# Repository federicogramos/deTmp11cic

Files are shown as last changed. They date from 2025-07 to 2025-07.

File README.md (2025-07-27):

# About
Dispositivo de control periódico.
- Firmware
- Pcb diseño altium de varias placas que componen distintas partes.
- Fuente de alimentacion switching step down diseñada aparte en otro proyecto aun no incluido.

# ./sw
Contiene el firmware para ser utilizado en el hw aqui especificado.

# Schematics
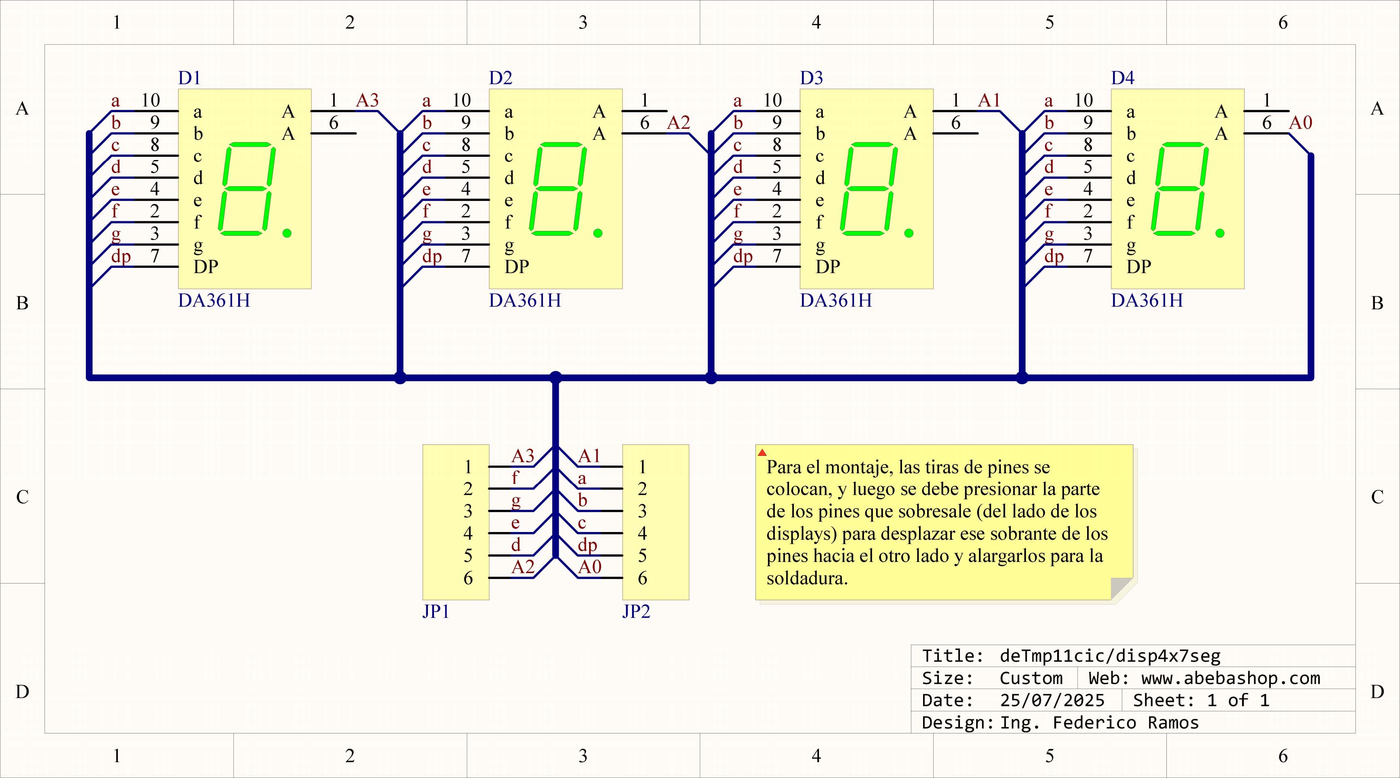
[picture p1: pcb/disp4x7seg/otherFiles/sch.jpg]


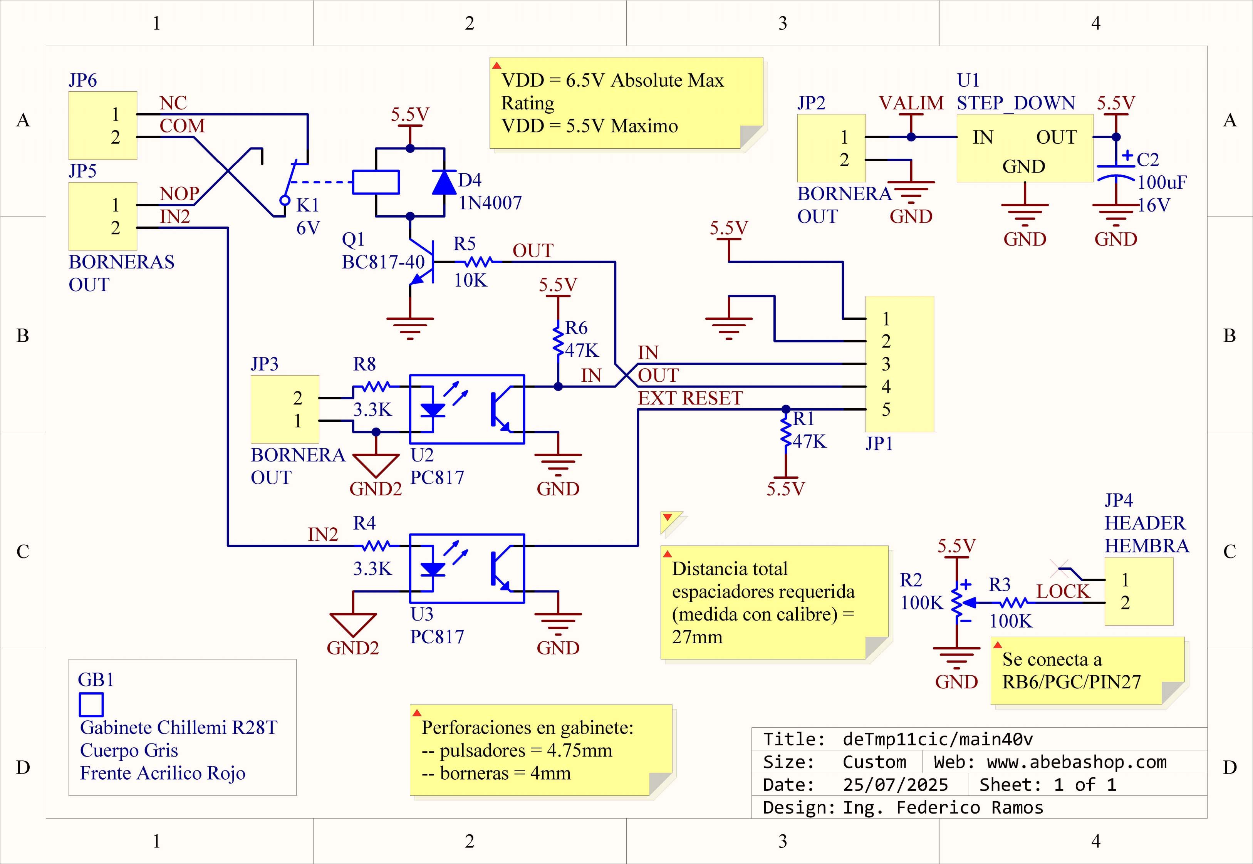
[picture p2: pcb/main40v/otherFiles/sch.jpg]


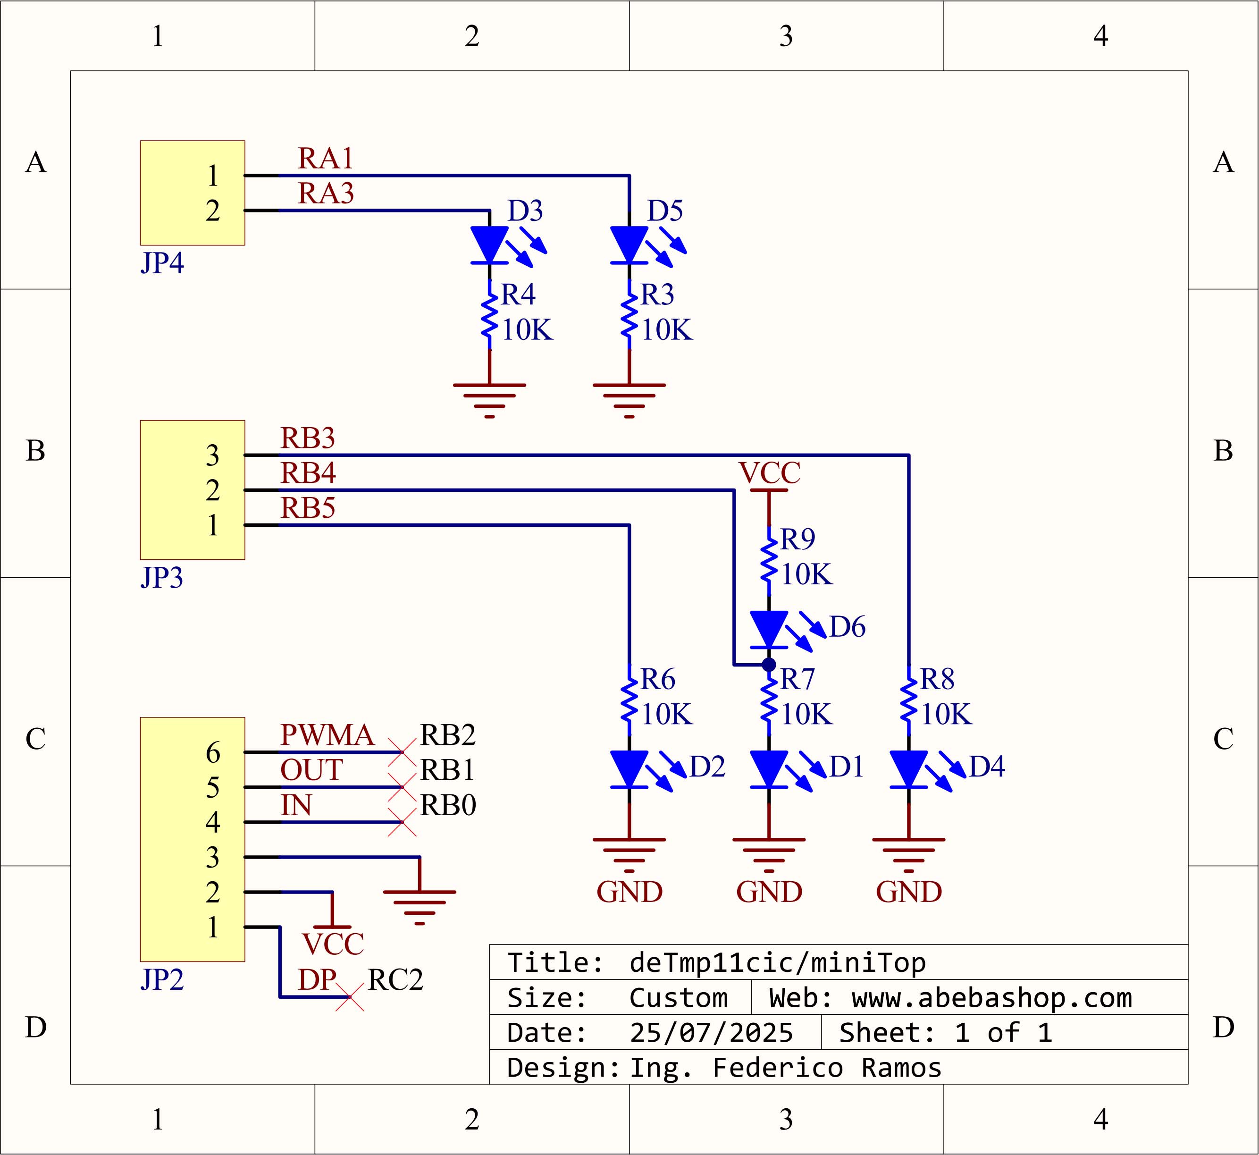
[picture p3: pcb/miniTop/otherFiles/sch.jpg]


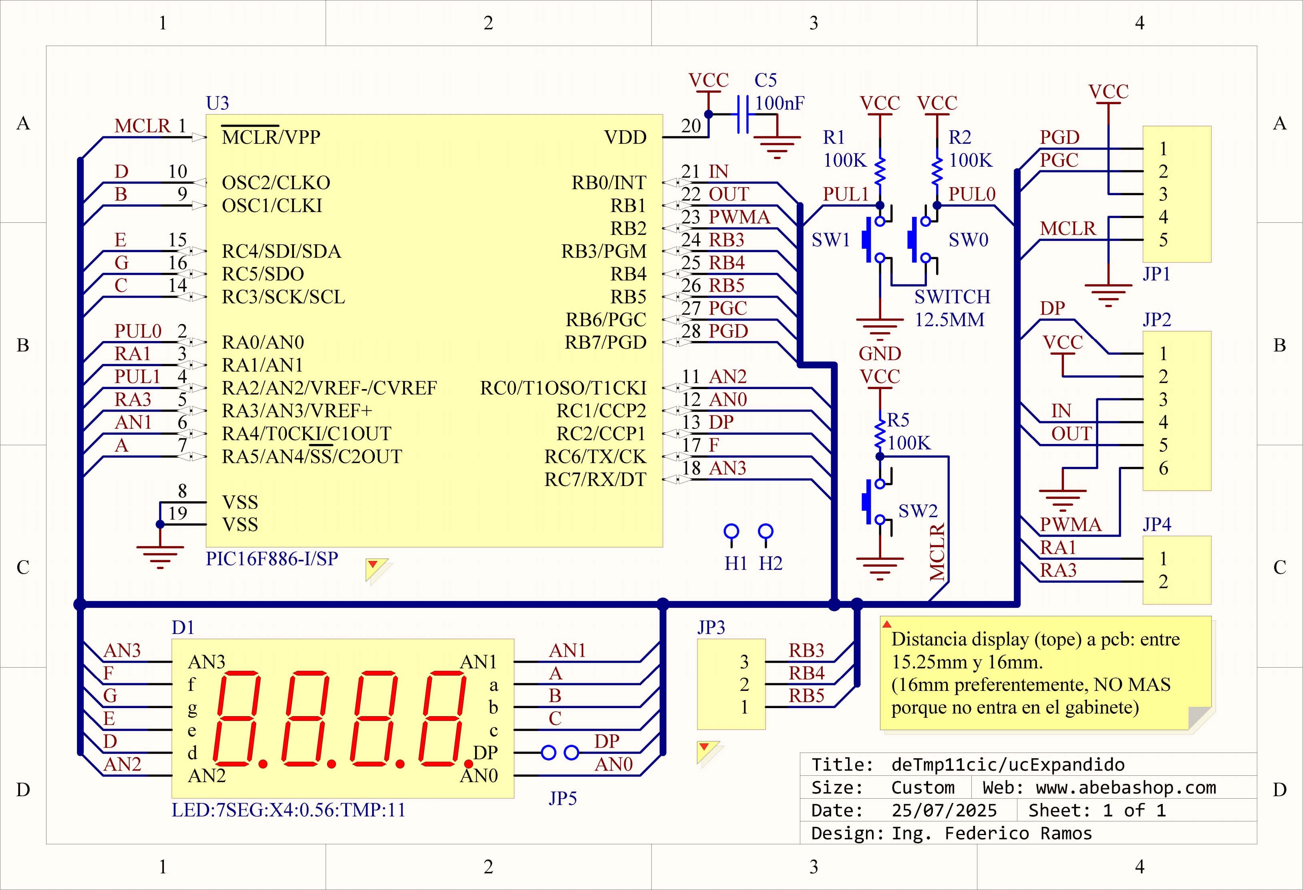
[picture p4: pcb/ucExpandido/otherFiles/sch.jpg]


# PCBs

### ucExpandido

Bottom overlay
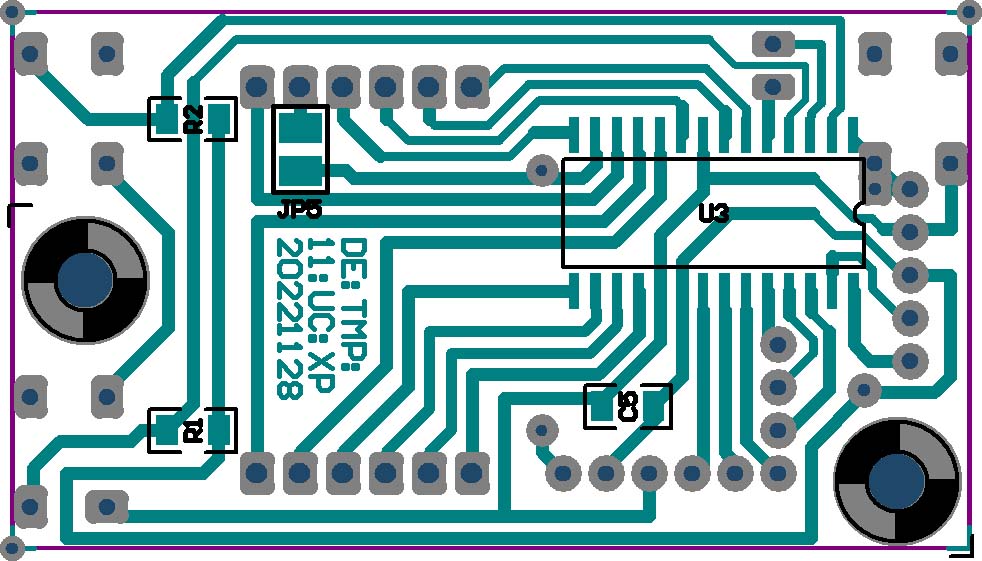
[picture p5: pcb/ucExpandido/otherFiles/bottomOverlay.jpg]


Top overlay
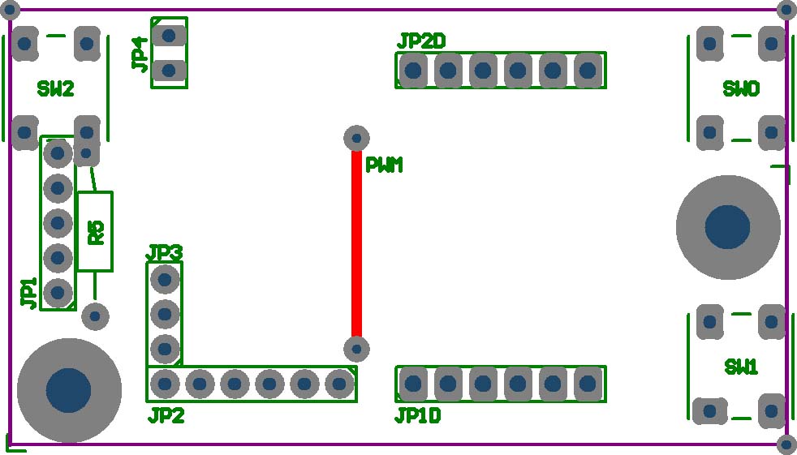
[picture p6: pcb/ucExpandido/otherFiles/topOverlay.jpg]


# Renderización cad
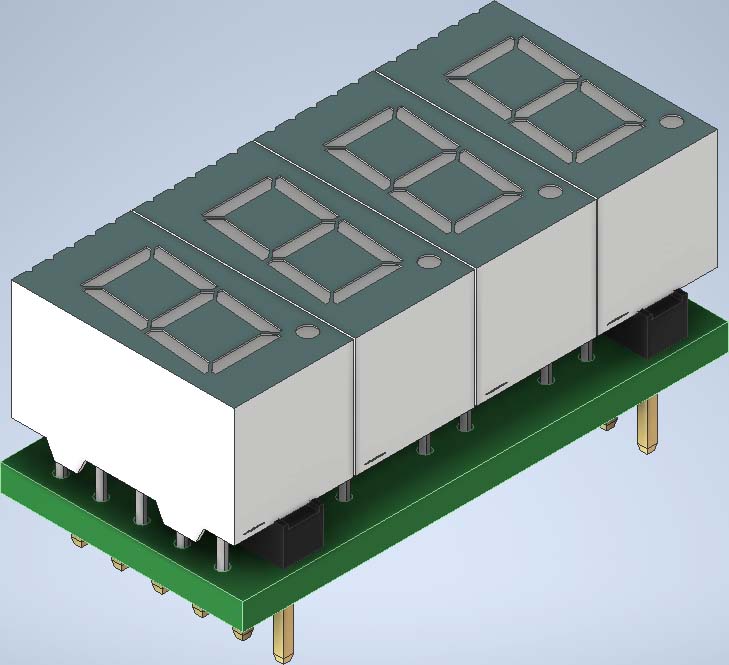
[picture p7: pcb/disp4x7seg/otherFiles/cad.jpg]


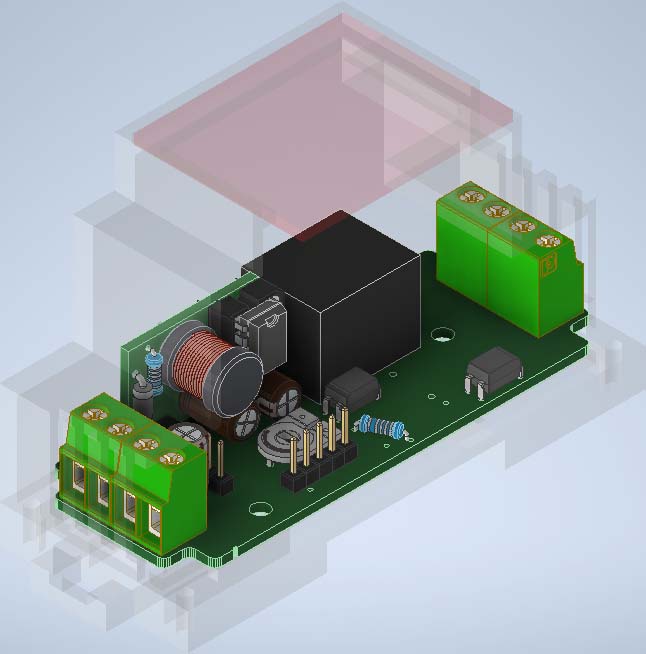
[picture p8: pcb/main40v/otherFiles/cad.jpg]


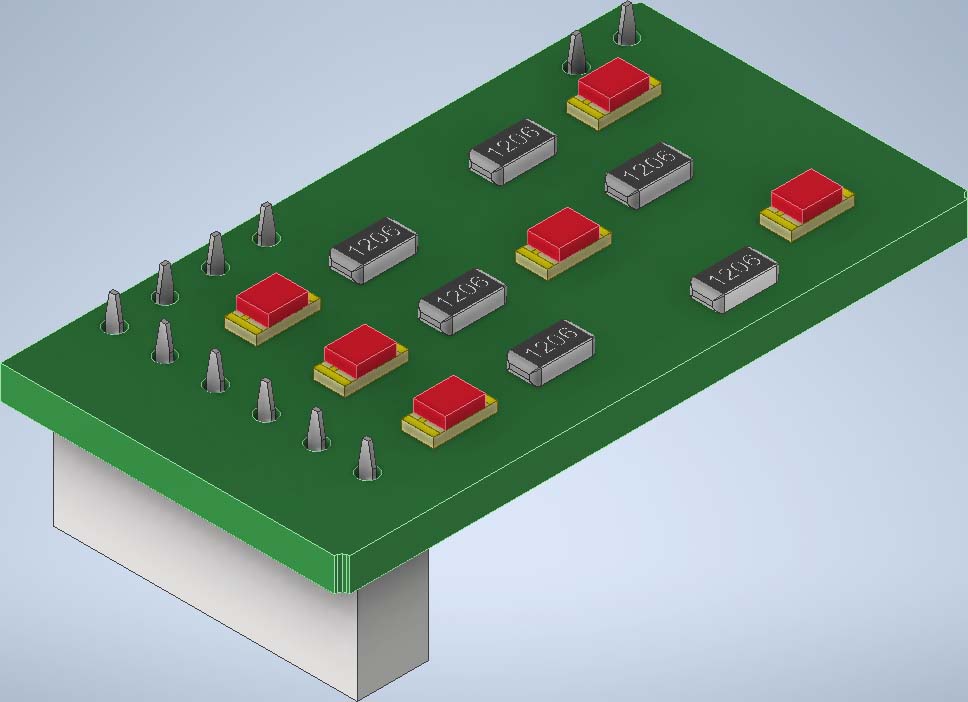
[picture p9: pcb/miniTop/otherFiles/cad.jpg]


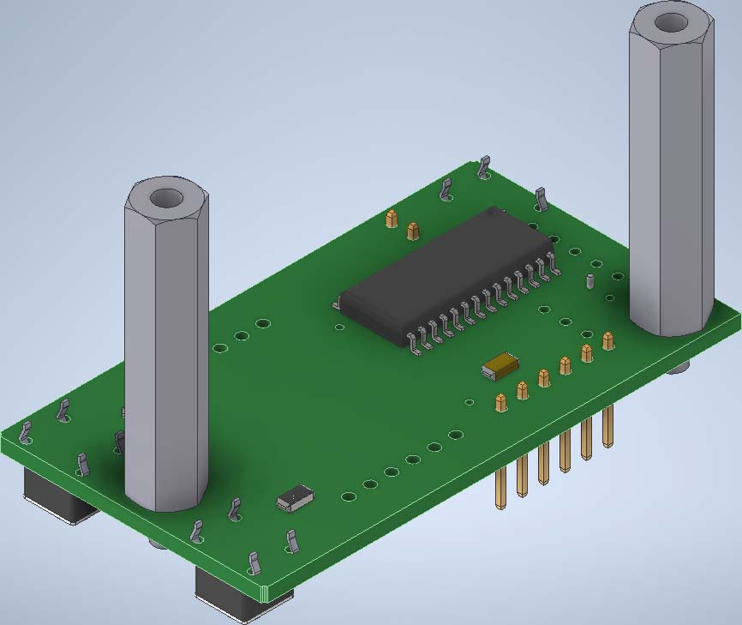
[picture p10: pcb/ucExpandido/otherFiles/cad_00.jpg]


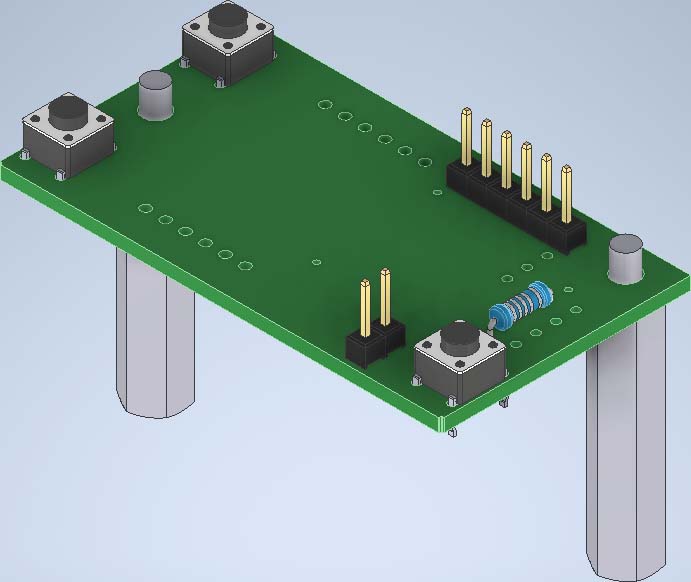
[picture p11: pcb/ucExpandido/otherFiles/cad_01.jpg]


# Modulos ensamblados

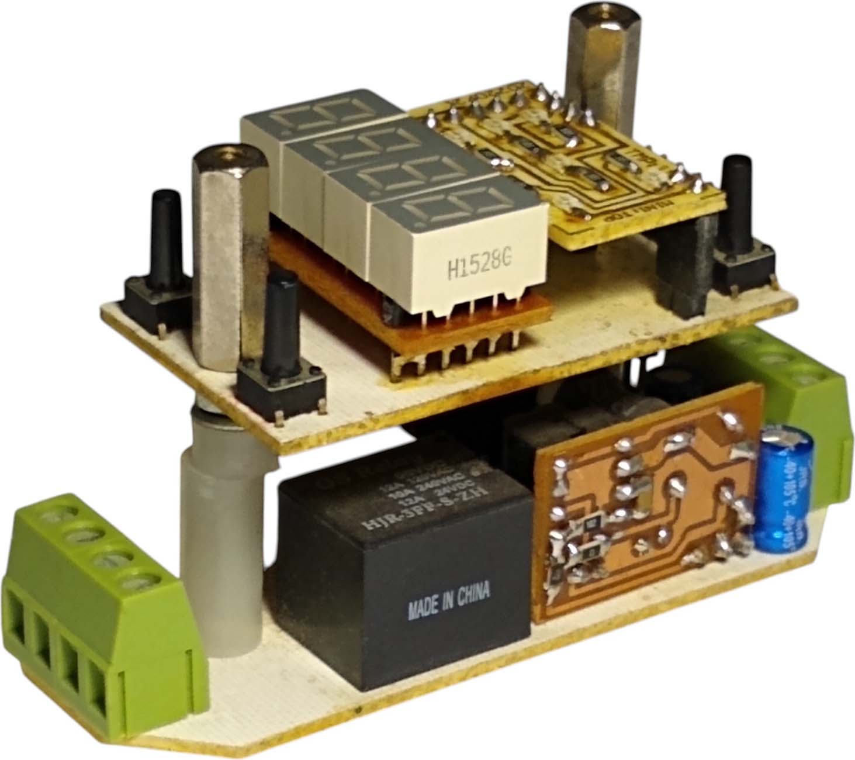
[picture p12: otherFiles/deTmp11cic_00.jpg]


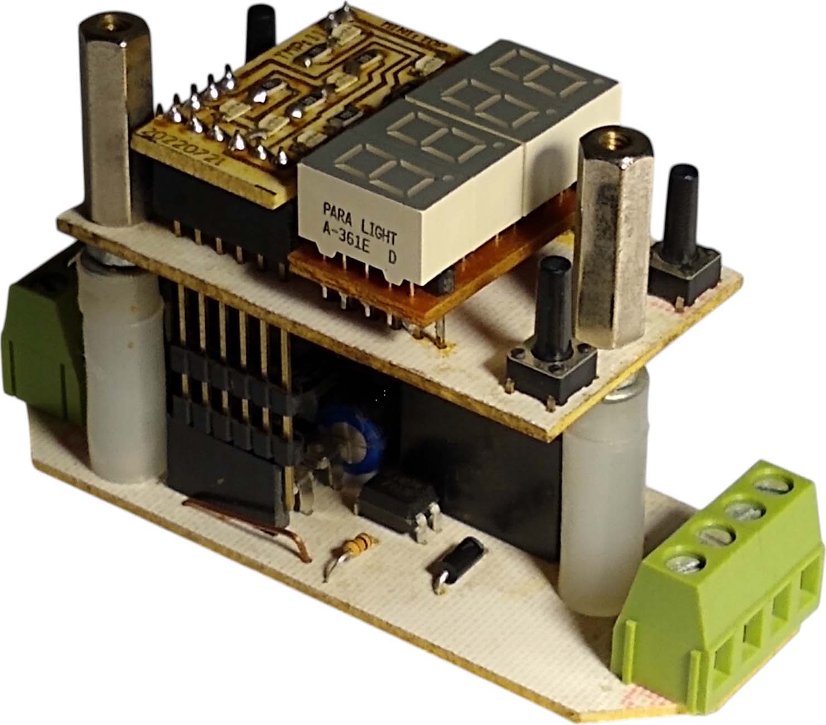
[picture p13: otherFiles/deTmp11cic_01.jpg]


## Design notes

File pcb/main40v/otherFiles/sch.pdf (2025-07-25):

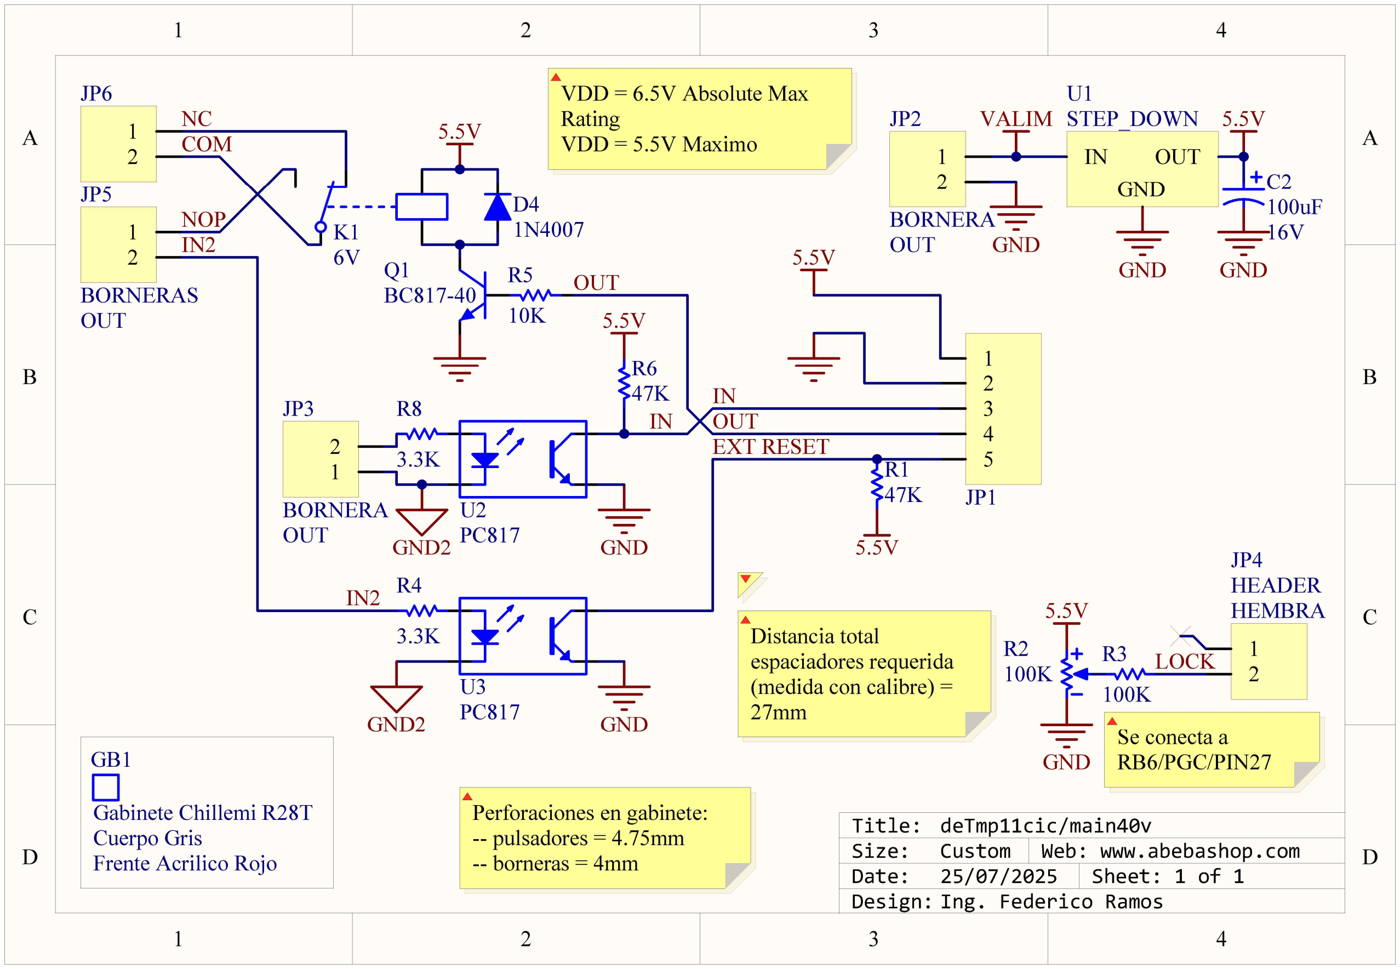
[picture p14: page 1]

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
BORNERA
OUT
JP2 | VALIM | 5.5V

D4
1N4007
Q1
BC817-40
10K

R5

K1
6V

47K

R6

5.5V

U2
PC817

1

2

BORNERA

JP3

OUT | GND

3.3K

R8

1
2

JP6

1
2
BORNERAS
OUT

JP5

IN

OUT

NC

NOP
5.5V

OUT

IN

COM | IN | OUT
| | GND

U1
STEP_DOWN

GND
GND

5.5V

100uF
16V

C2

Cuerpo Gris
Frente Acrilico Rojo

GB1

Gabinete Chillemi R28T

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
EXT RESET

5.5V
HEADER

1
2

JP4

HEMBRA

100K

R2

5.5V

GND

LOCK
100K

R3
U3
PC817

3.3K

R4

GND

IN2

IN2

GND2

GND2

Title:
Size:
Date: | Sheet:
Design:

25/07/2025

| Web: www.abebashop.com
| Sheet: 1 of 1
| Ing. Federico Ramos

deTmp11cic/main40v
Custom

Se conecta a
RB6/PGC/PIN27

VDD = 6.5V Absolute Max
Rating
VDD = 5.5V Maximo

Distancia total
espaciadores requerida
(medida con calibre) =
27mm

Perforaciones en gabinete: -- pulsadores = 4.75mm
-- borneras = 4mm

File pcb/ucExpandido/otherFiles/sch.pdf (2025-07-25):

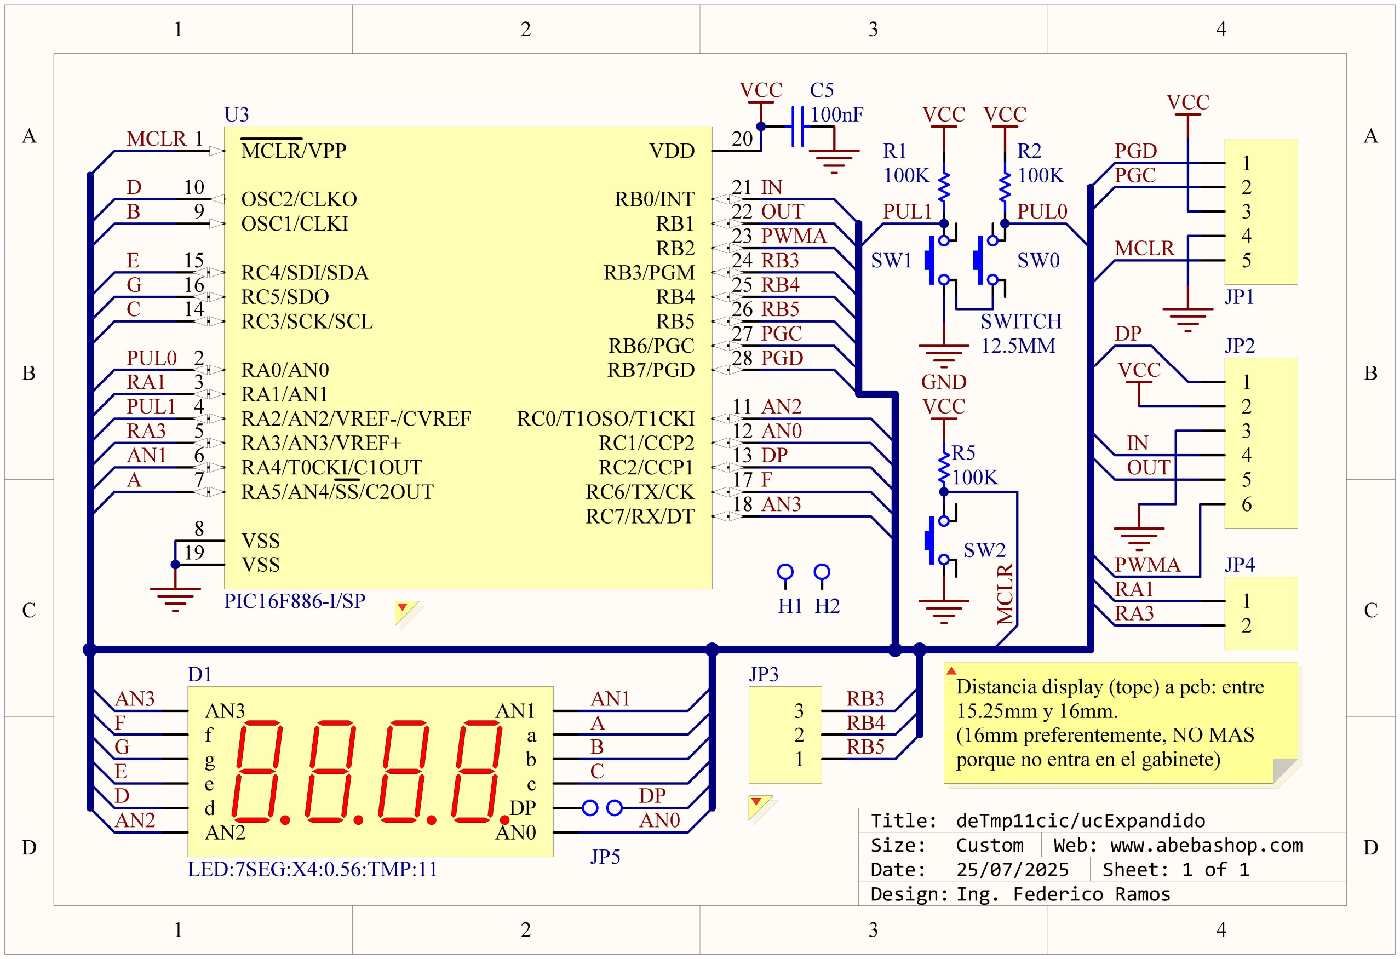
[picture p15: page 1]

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
A A MCLR/VPP 1

RA0/AN0 2
RA1/AN1 3
RA2/AN2/VREF-/CVREF 4
RA3/AN3/VREF+ 5
RA4/T0CKI/C1OUT 6
RA5/AN4/SS/C2OUT 7

VSS 8

OSC1/CLKI 9

OSC2/CLKO 10

RC0/T1OSO/T1CKI | 11
RC1/CCP2 | 12
RC2/CCP1 | 13

RC3/SCK/SCL 14

RC4/SDI/SDA 15
RC5/SDO 16
RC6/TX/CK | 17
RC7/RX/DT | 18

VSS 19

VDD | 20
RB0/INT | 21
RB1 | 22
RB2 | 23
RB3/PGM | 24
RB4 | 25
RB5 | 26
RB6/PGC | 27
RB7/PGD | 28

U3

PIC16F886-I/SP

VCC
100nF

C5

MCLR

PUL0

PUL1

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
H1 H2

100K

R2
100K

R1

VCC

PUL1 | PUL0

12.5MM

SW0

SWITCH

SW1

GND
VCC

100K

R5

AN2

AN3 | AN1

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
MCLR

VCC

VCC

OUT

IN

VCC

PWMA

SW2 MCLR

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
JP2 DP

PWMA
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
LED:7SEG:X4:0.56:TMP:11

Title:
Size:
Date: | Sheet:
Design:

25/07/2025

| Web: www.abebashop.com
| Sheet: 1 of 1
| Ing. Federico Ramos

deTmp11cic/ucExpandido
Custom

Distancia display (tope) a pcb: entre 15.25mm y 16mm.
(16mm preferentemente, NO MAS porque no entra en el gabinete)

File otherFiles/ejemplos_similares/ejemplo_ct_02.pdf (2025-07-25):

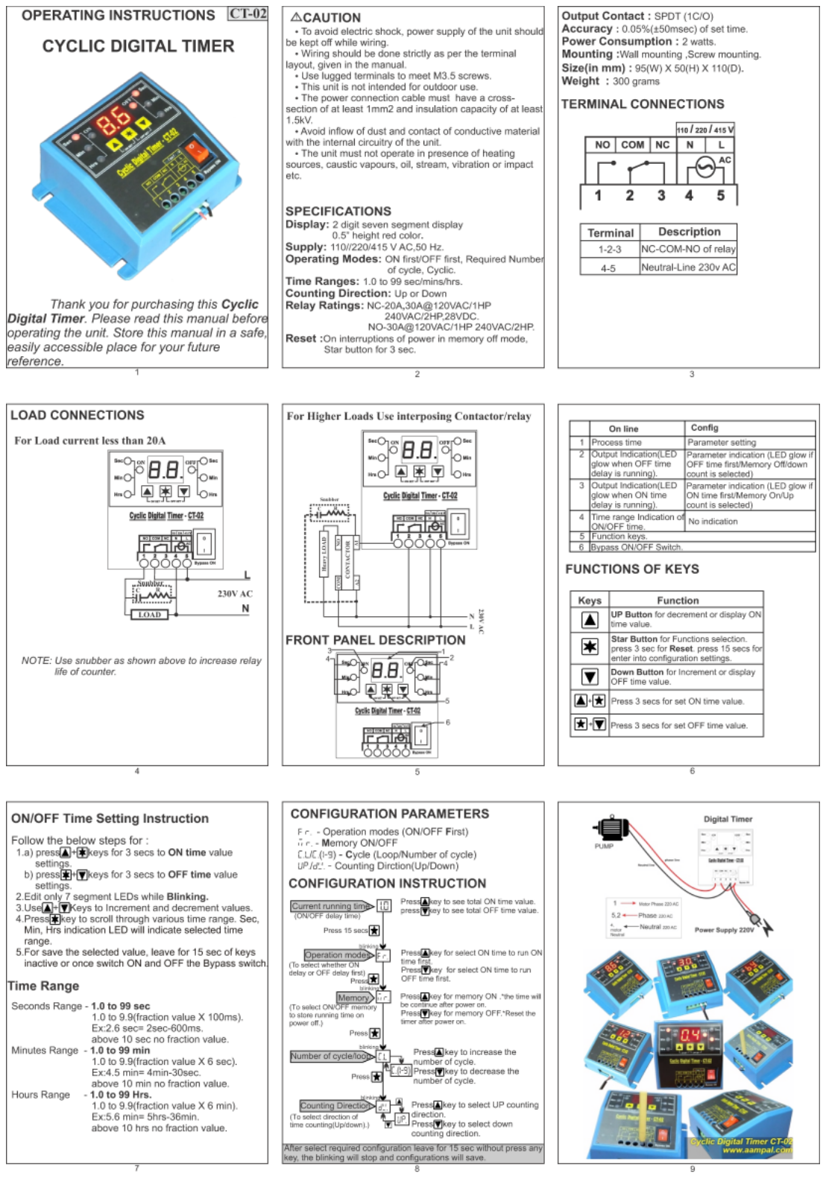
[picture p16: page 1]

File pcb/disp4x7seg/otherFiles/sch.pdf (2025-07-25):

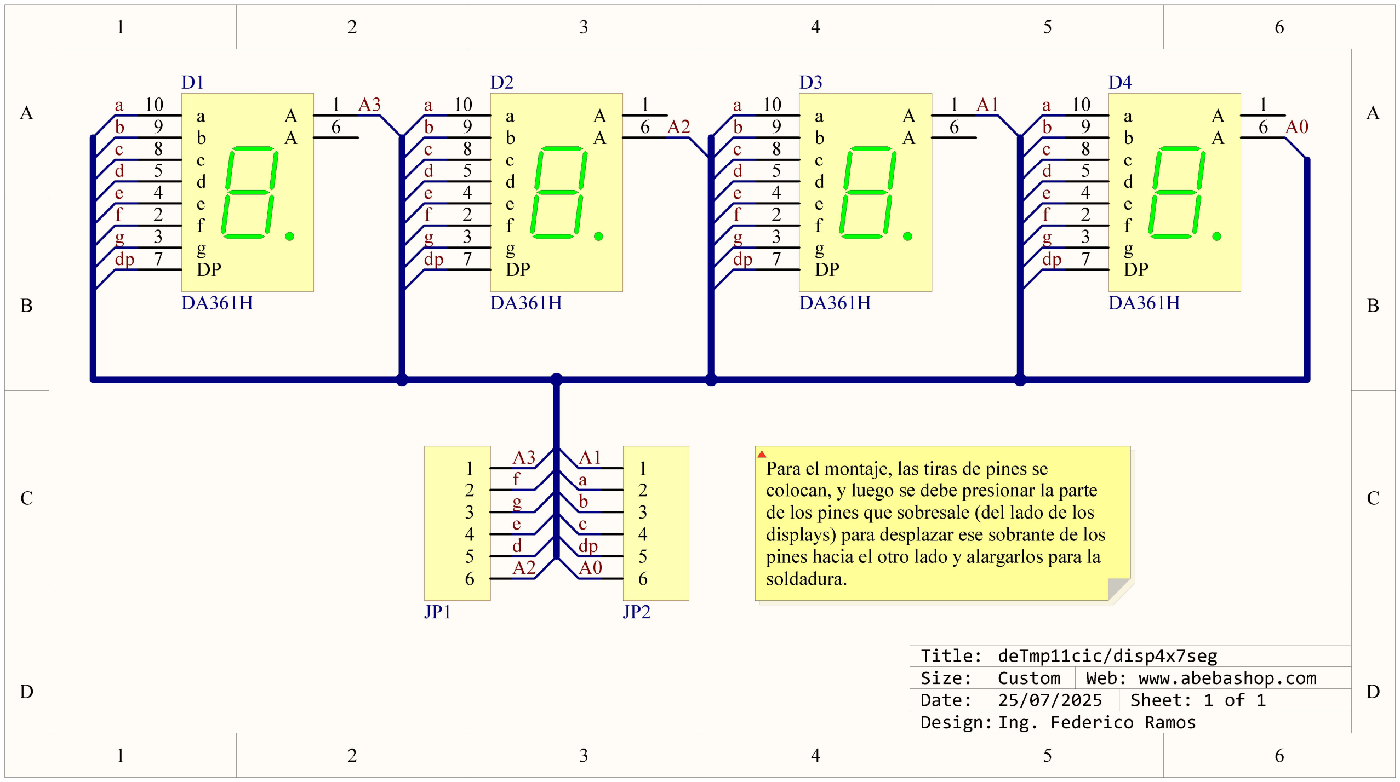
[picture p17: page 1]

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
A A A

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
DP 7

b

9

a

10

D2

DA361H

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
DP 7

b

9

a

10

D1

DA361H

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
DP 7

b

9

a

10

D3

DA361H

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
DP 7

b

9

a

10

D4

DA361H

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
Title:
Size:
Date: | Sheet:
Design:

25/07/2025

| Web: www.abebashop.com
| Sheet: 1 of 1
| Ing. Federico Ramos

deTmp11cic/disp4x7seg
Custom

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
Para el montaje, las tiras de pines se colocan, y luego se debe presionar la parte de los pines que sobresale (del lado de los displays) para desplazar ese sobrante de los pines hacia el otro lado y alargarlos para la soldadura.

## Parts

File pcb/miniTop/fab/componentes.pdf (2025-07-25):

Designator | Description | N
D1, D2, D3, D4, D5, D6 | Led 5mm Rojo Difuso | 6
R3, R4, R6, R7, R8, R9 | Resistencia 1206; 10Kohm | 6
Designator | Description | N
JP2 | Header6x1 | 1
JP3 | Header3x1 | 1
JP4 | Header2x1 | 1
Designator | Description | N

Bottom Layer

Top Layer

No se suelda

DE:TMP:11:MINI:TOP

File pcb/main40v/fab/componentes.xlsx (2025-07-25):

DE:TMP:11:MAIN:STEP
Placa principal con borneras de e/s y relay.
Bottom Layer
Designator | Description | N
Q1 | BC817-40 SMD | 1
R3 | Resistencia 1206; 1Kohm | 1
R6 | Resistencia 1206; 47Kohm | 1
R4, R8 | Resistencia 1206; 3.3Kohm | 2
R5 | Resistencia 1206; 10Kohm | 1
Top Layer
Designator | Description | N
R1 | Resistencia 47Kohm / 0.25W | 1
C2 | Capacitor Electrolítico 100uF / 16V | 1
D4 | 1N4007 | 1
JP1 | Header 5x1 / Hembra (si se usa tira de pines 40x1, resultan 4 pares de unidades útiles usadas para JP1 y JP4) | 0.25
JP4 | Header 2x1 / Hembra | 0
JP2, JP3, JP5, JP6 | Bornera Tornillos 2x1; Altura = 13.8mm | 4
K1 | Relay 6V / 1 inversor | 1
R2 | Preset Cuerpo Desnudo 10K / Ajuste Vertical | 1
U1 | Modulo Step Down | 1
U2, U3 | PC817 | 2
No se suelda
Designator | Description | N
GB1 | Gabinete Chillemi R28T | 1
- | Tuerca | 2
- | Espaciador 5mm | 2
- | Espaciador 20mm | 2
- | Tornillo 38mm cabeza fresada | 2

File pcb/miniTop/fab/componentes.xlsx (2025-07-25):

DE:TMP:11:MINI:TOP
-
Bottom Layer
Designator | Description | N
D1, D2, D3, D4, D5, D6 | Led 5mm Rojo Difuso | 6
R3, R4, R6, R7, R8, R9 | Resistencia 1206; 10Kohm | 6
Top Layer
Designator | Description | N
JP2 | Housing para PCB 6x1 | 1
JP3 | Housing para PCB 3x1 | 1
JP4 | Housing para PCB 2x1 | 1
No se suelda
Designator | Description | N

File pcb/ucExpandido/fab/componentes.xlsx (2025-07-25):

DE:TMP:11:UC:EXPANDIDO
Placa uc expandido.
Bottom Layer
Designator | Description | N
JP1 | Header5x1 / Macho (1 unidad, funcionallidad = programación) | 1
- | Header 40x1 (Para JP1: 0.17 alcanza para 1 de 5x1) | 0.17
JP2 | Header6x1 / Largo=35mm (1 unidad) | 1
JP3 | Header3x1 / Largo=35mm (1 unidad) | 1
JP4 | Header2x1 / Largo=35mm (1 unidad) | 1
- | CGrid Header Recto 40x1 / Largo=35mm / Paso=2.54mm (0.5 alcanza para JP2+JP3+JP4) | 0.5
SW0, SW1, SW2 | Touch Switch / Alto = 12.5mm | 3
D1 | Módulo placa LED:7SEG:X4:0.56:TMP:11 | 1
Top Layer
Designator | Description | N
C5 | Capacitor 1206; 100nF; 50V (1uF alternativamente) | 1
R1, R2, R5 | Resistencia 1206; 100Kohm | 3
U3 | PIC16F886-I/SP | 1
No se suelda
Designator | Description | N
JP5 | Jumper 2 contactos; Soldadura | 1

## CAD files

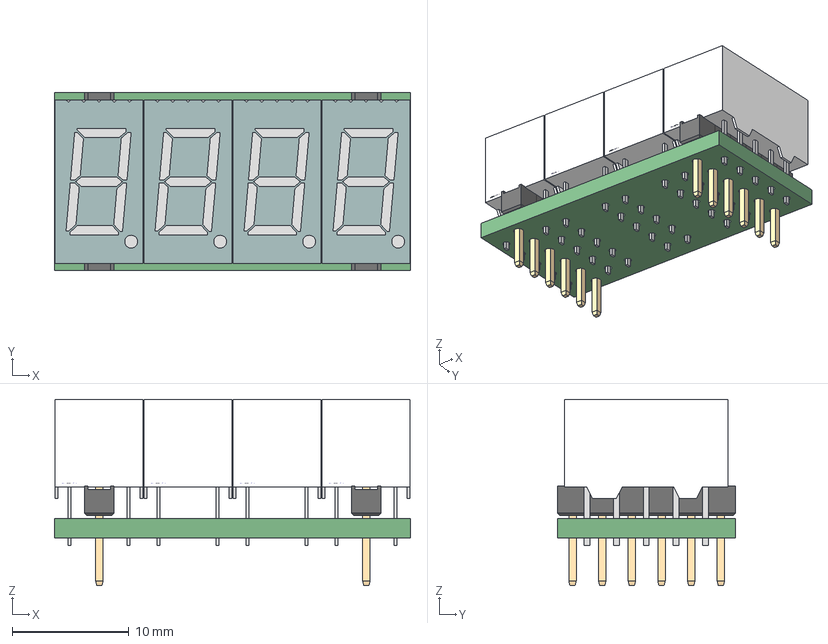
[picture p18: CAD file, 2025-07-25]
pcb/disp4x7seg/disp4x7seg.step
30.5 x 15.3 x 15.9 mm
Board
pin x 12
SW3dPS-Disp_SA36-11_Disp_SA36-12 x 4

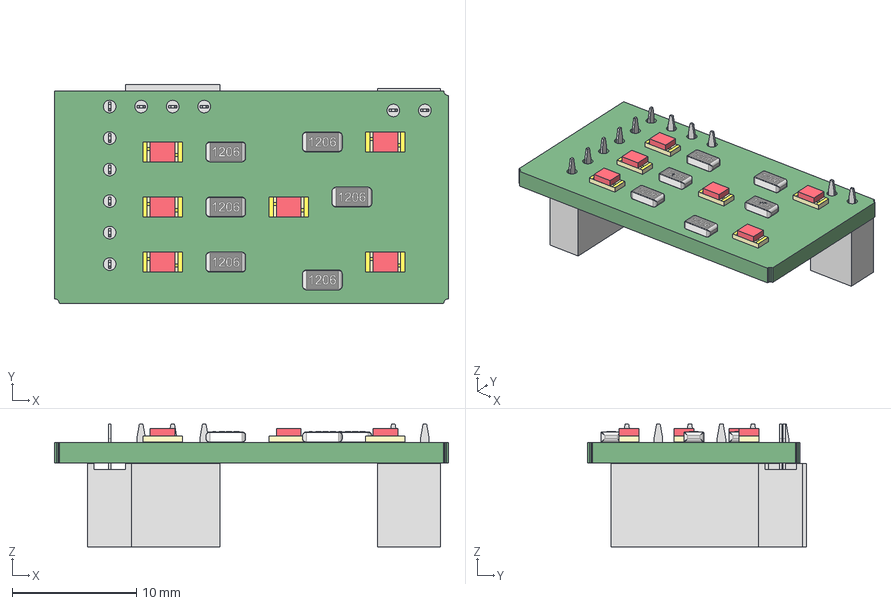
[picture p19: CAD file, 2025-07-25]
pcb/miniTop/miniTop.step
31.8 x 17.7 x 9.91 mm
Board x 7
r1206 x 6
Extruded2 x 6
Extruded1 x 6
Extruded x 12
Extruded4 x 6
Extruded3 x 6
3x1_cgrid_housing_pcb
6x1_cgrid_housing_pcb
2x1_cgrid_housing_pcb

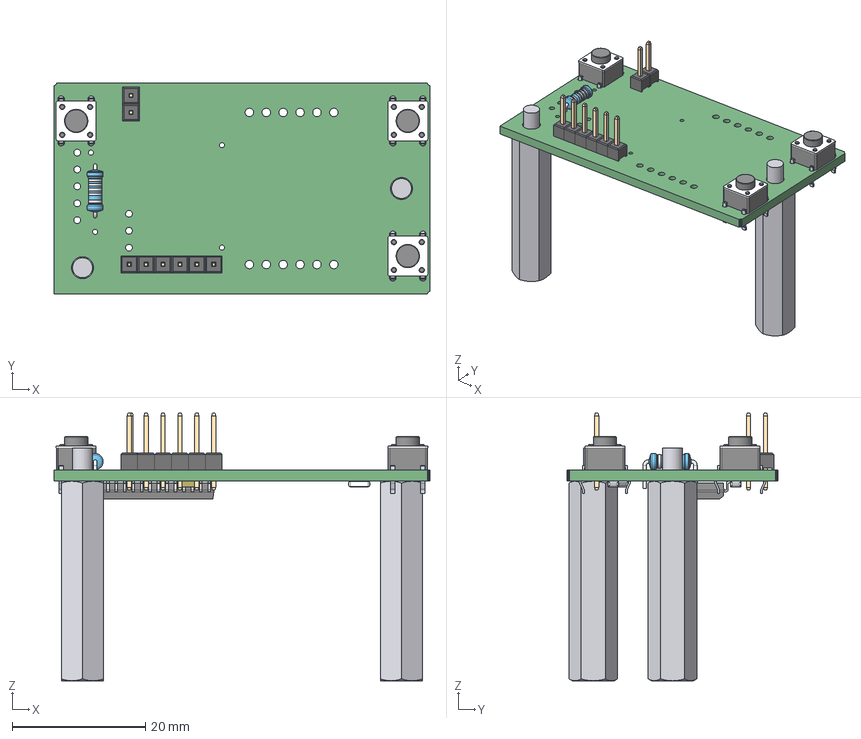
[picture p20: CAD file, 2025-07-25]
pcb/ucExpandido/ucExpandido.step
56.5 x 31.7 x 40.2 mm
Board
touch_5mm x 3
#5-UNC_TAMECO_30MM x 2
c1206
SOIC28
User_Library-MFR-25_MFR50S_(300mils)_Leads
User_Library-MFR-25_MFR50S_(300mils)_Band4
User_Library-MFR-25_MFR50S_(300mils)_Band2
User_Library-MFR-25_MFR50S_(300mils)_Band5
User_Library-MFR-25_MFR50S_(300mils)_Band1
User_Library-MFR-25_MFR50S_(300mils)_Band3
User_Library-MFR-25_MFR50S_(300mils)_Core
r1206 x 2
pin x 8

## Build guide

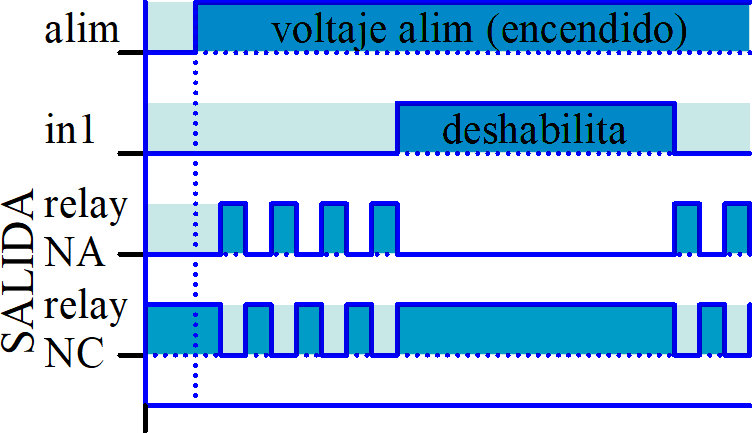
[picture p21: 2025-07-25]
manual/otherFiles/curva_deshabilita.png

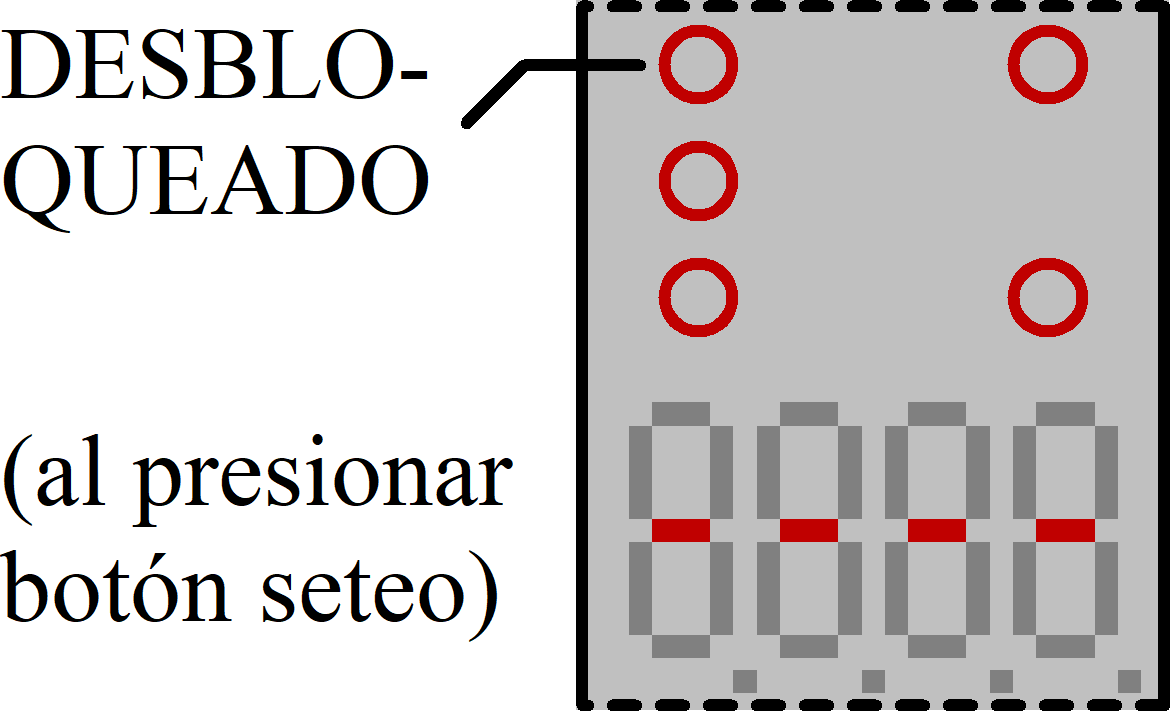
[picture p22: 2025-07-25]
manual/otherFiles/display_bloqueado.png

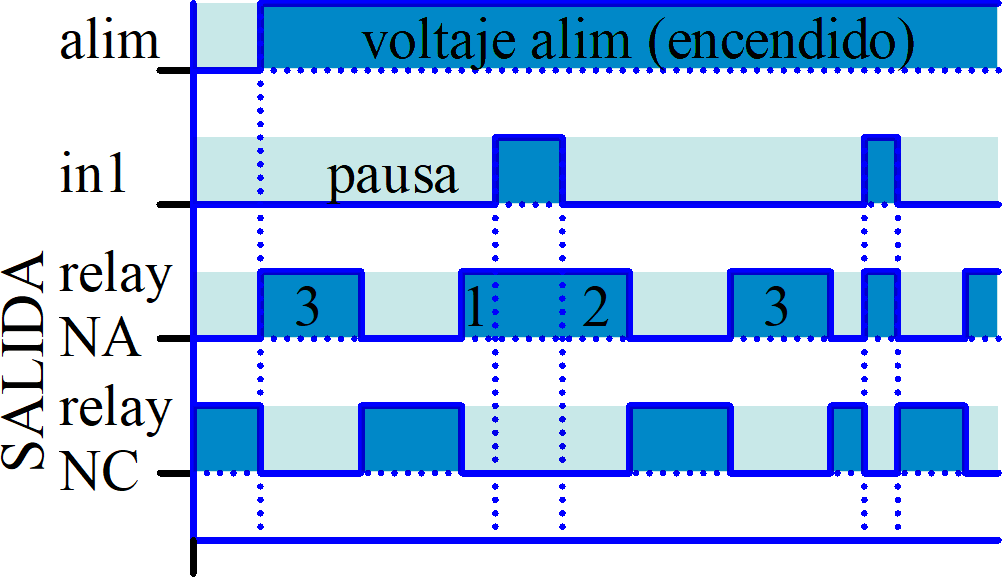
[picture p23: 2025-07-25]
manual/otherFiles/curva_pause_on.png

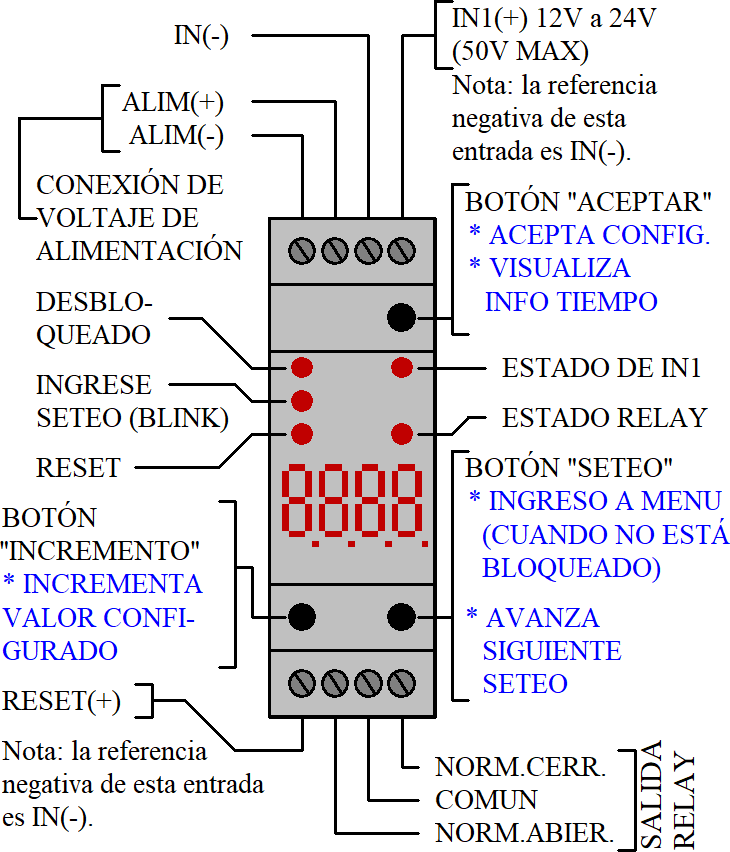
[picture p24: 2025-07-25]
manual/otherFiles/vista_frontal.png

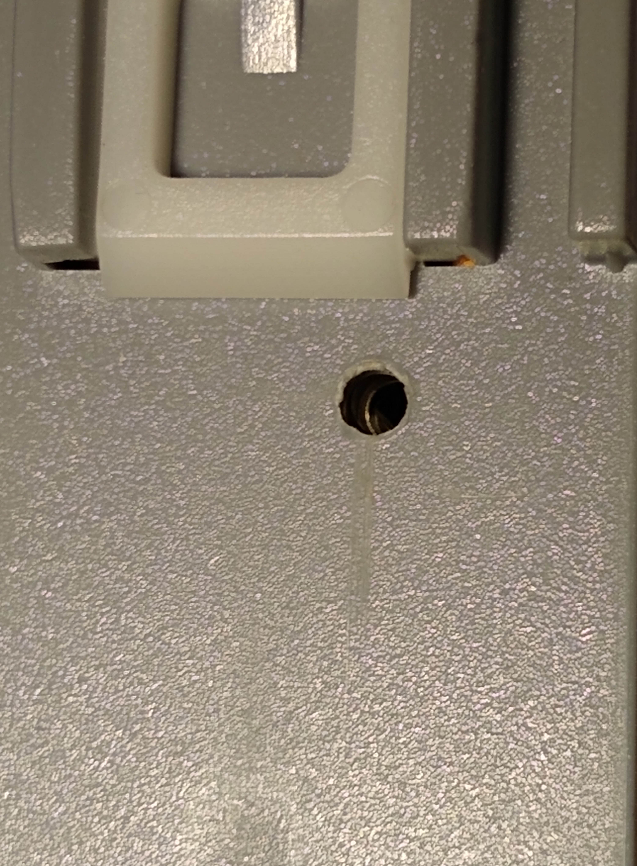
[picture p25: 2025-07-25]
manual/otherFiles/foto_preset_gabinete.jpg

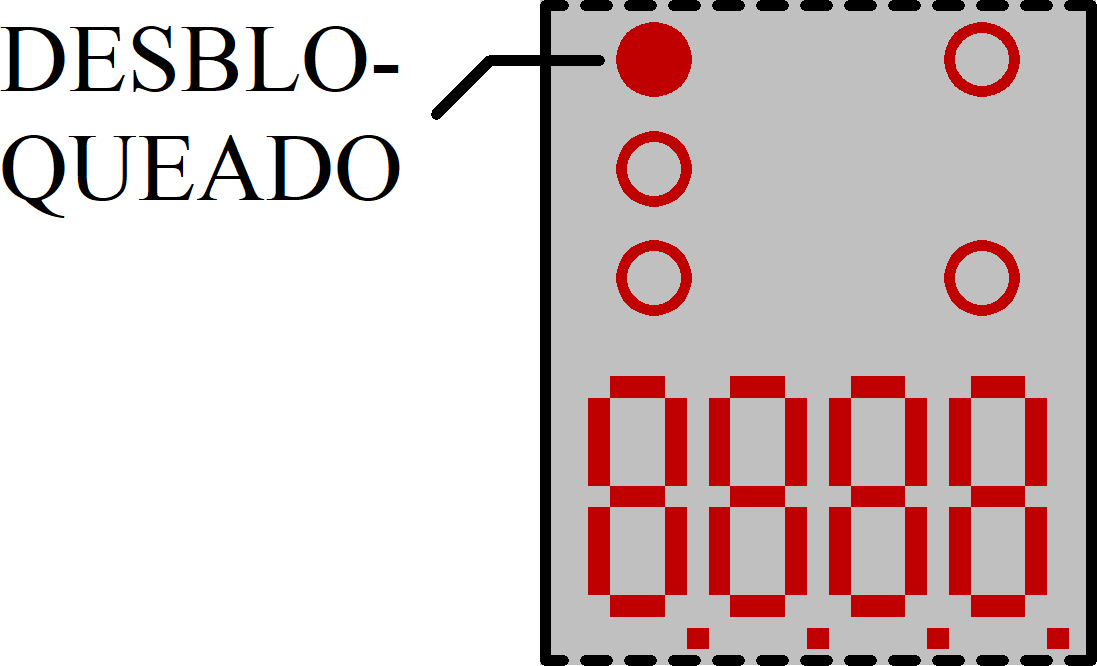
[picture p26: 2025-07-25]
manual/otherFiles/display_desbloqueado.png

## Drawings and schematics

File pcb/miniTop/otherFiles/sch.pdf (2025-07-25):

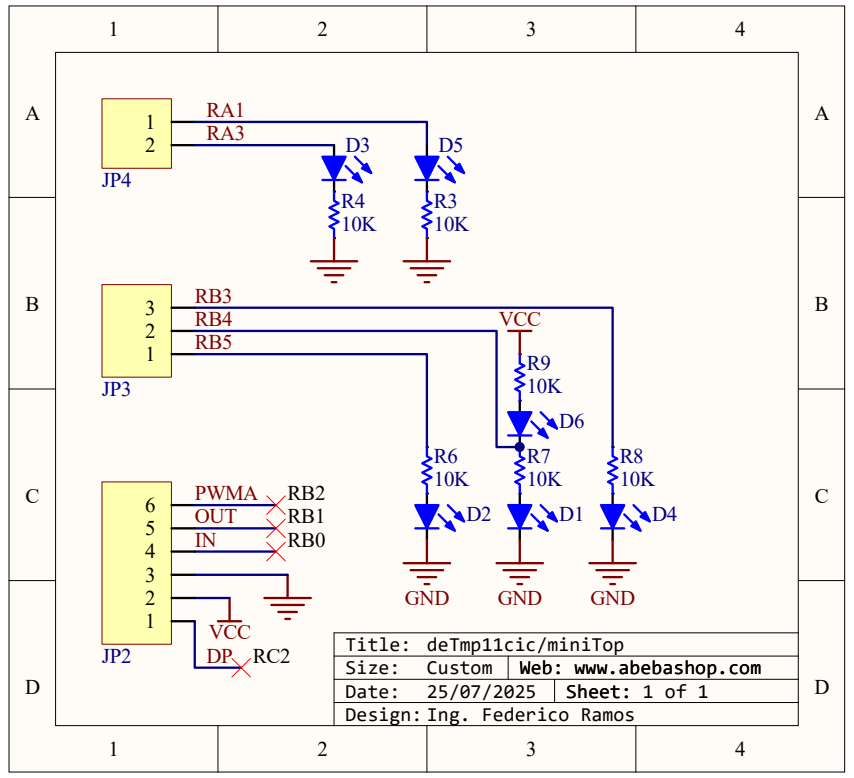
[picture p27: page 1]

Web: www.abebashop.com
Sheet: 1 of 1

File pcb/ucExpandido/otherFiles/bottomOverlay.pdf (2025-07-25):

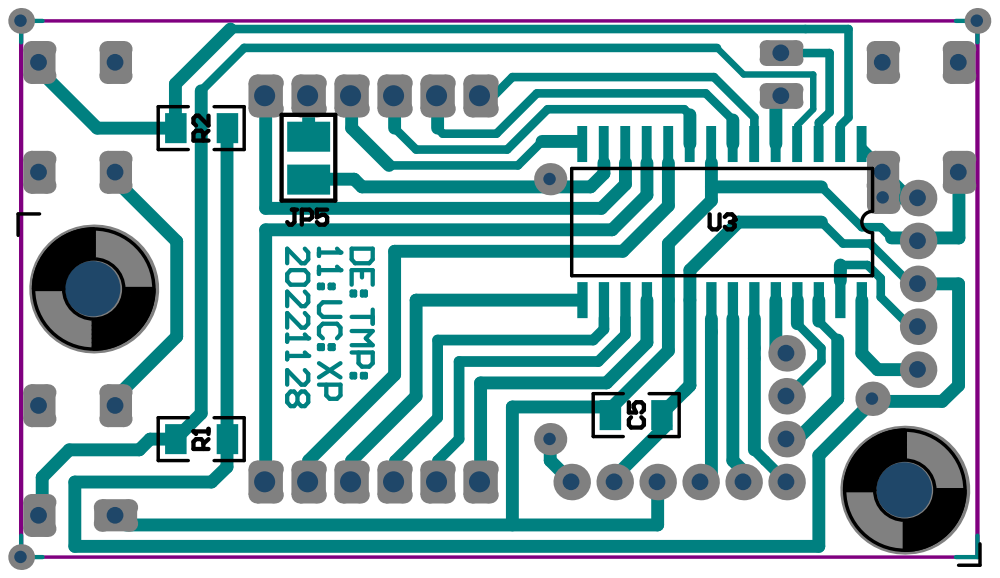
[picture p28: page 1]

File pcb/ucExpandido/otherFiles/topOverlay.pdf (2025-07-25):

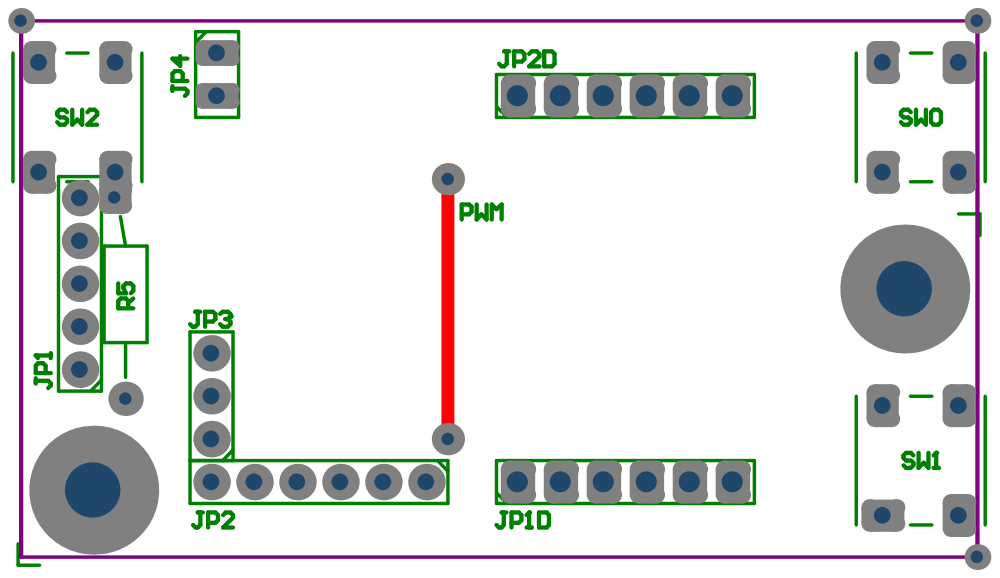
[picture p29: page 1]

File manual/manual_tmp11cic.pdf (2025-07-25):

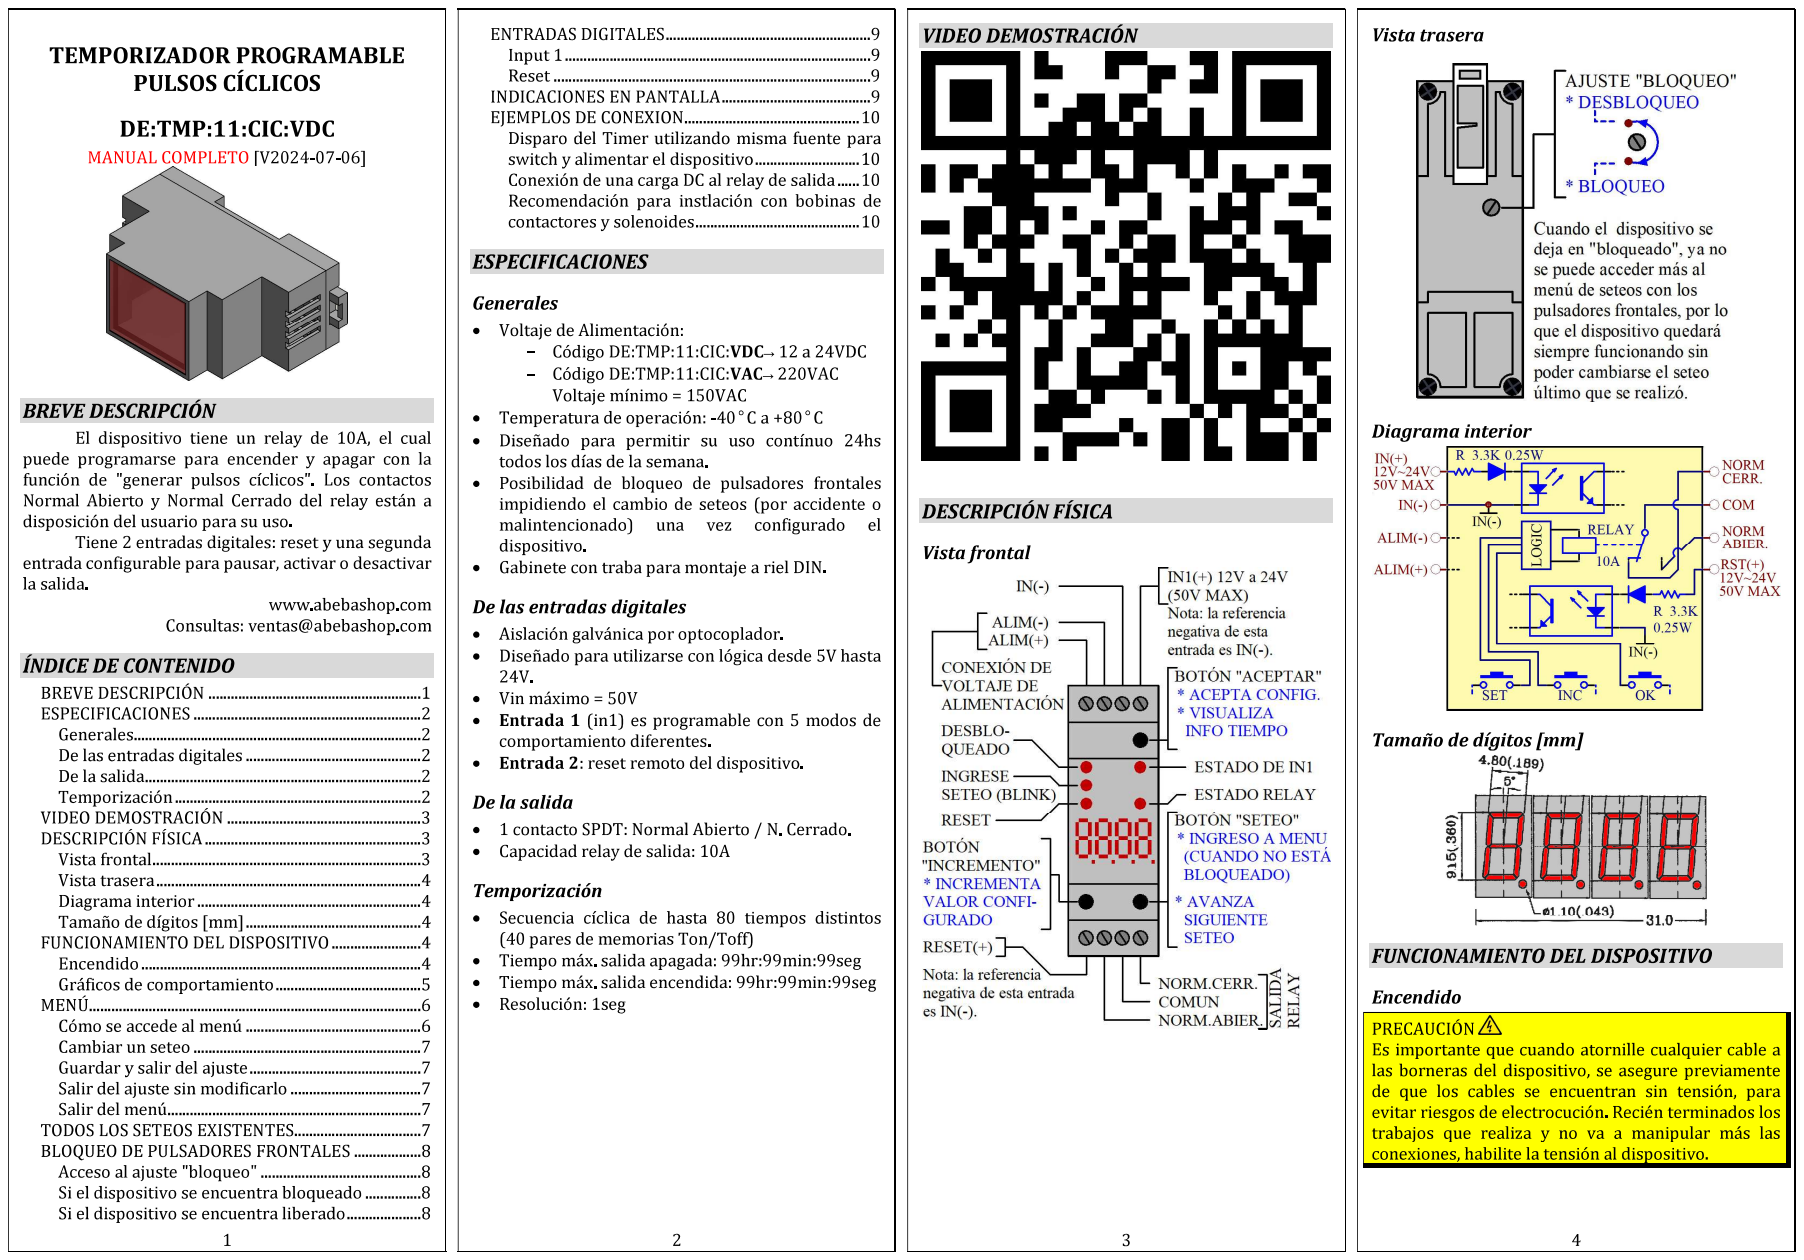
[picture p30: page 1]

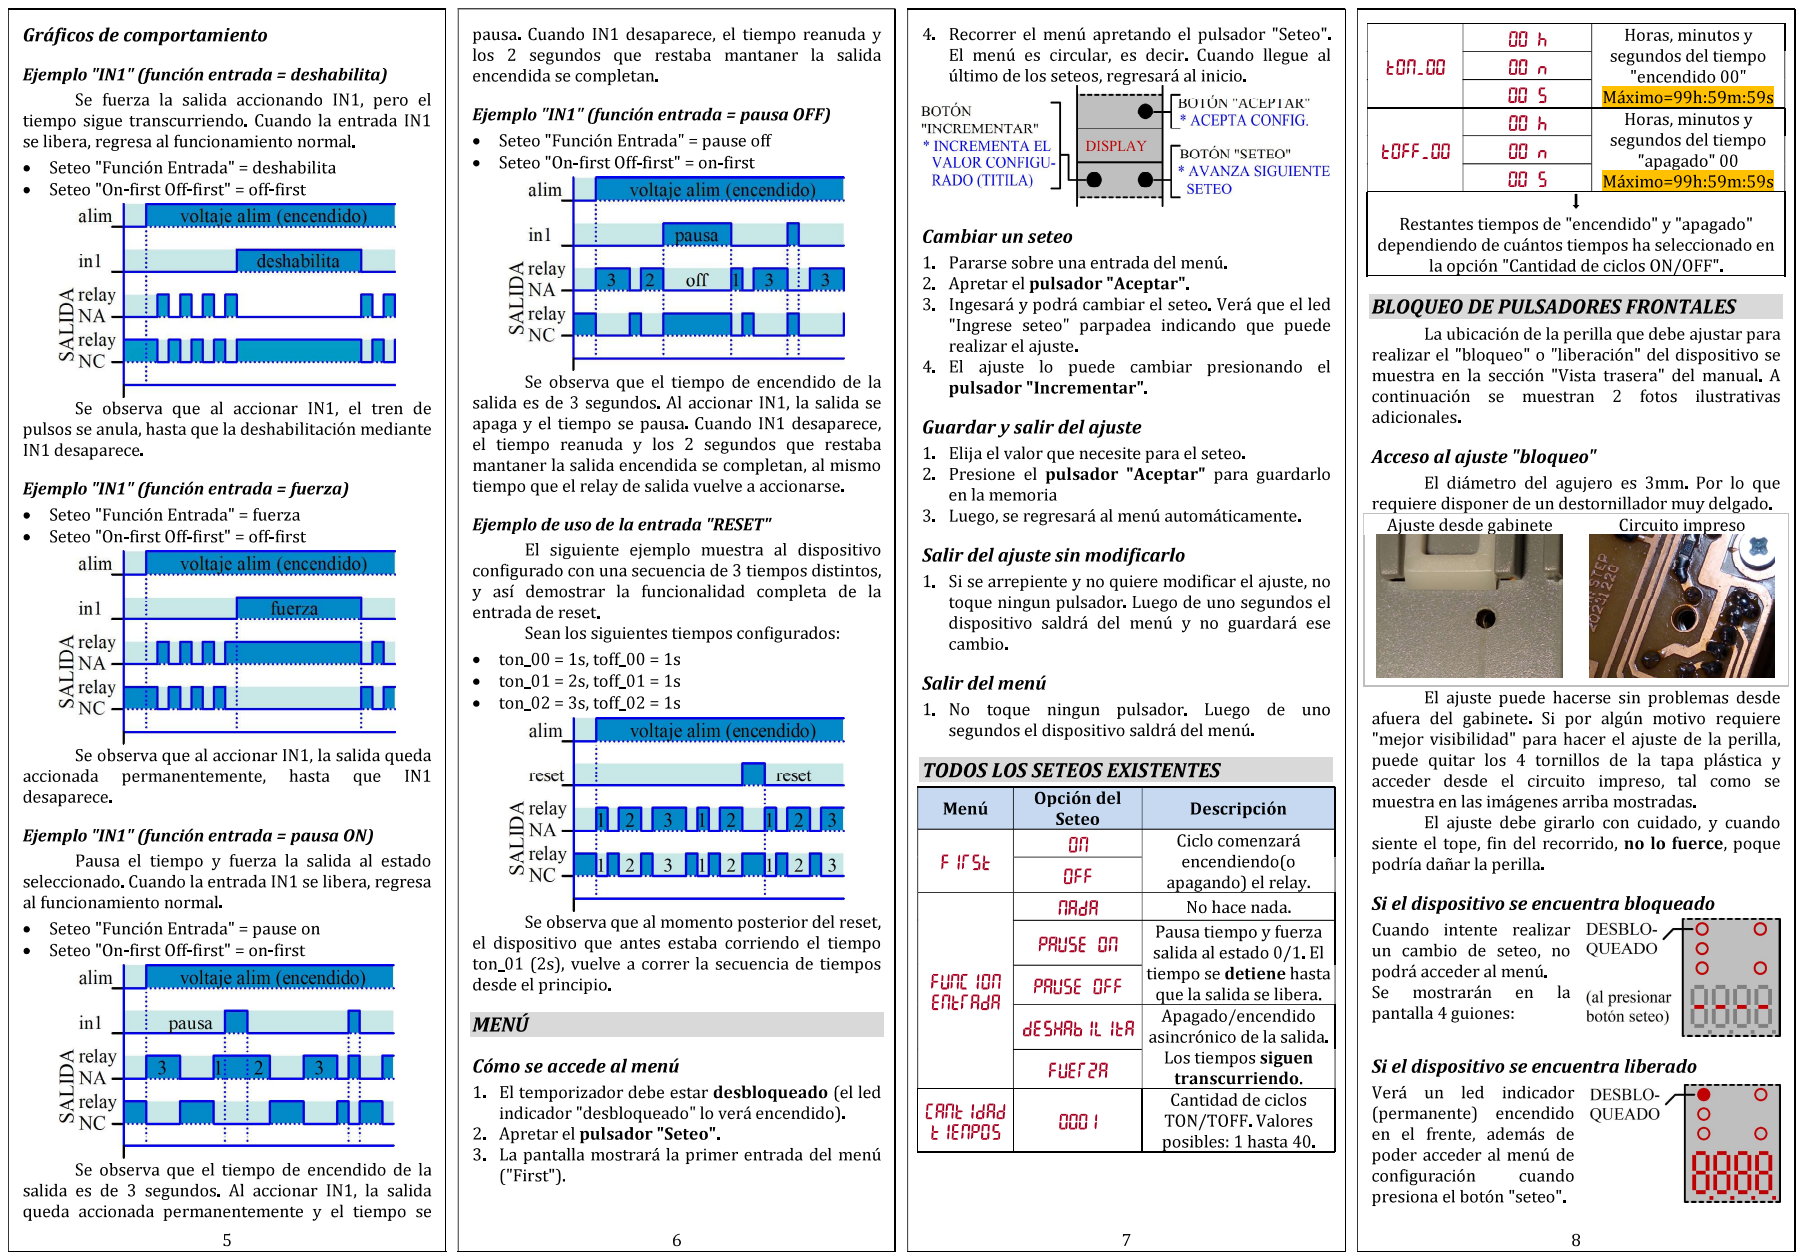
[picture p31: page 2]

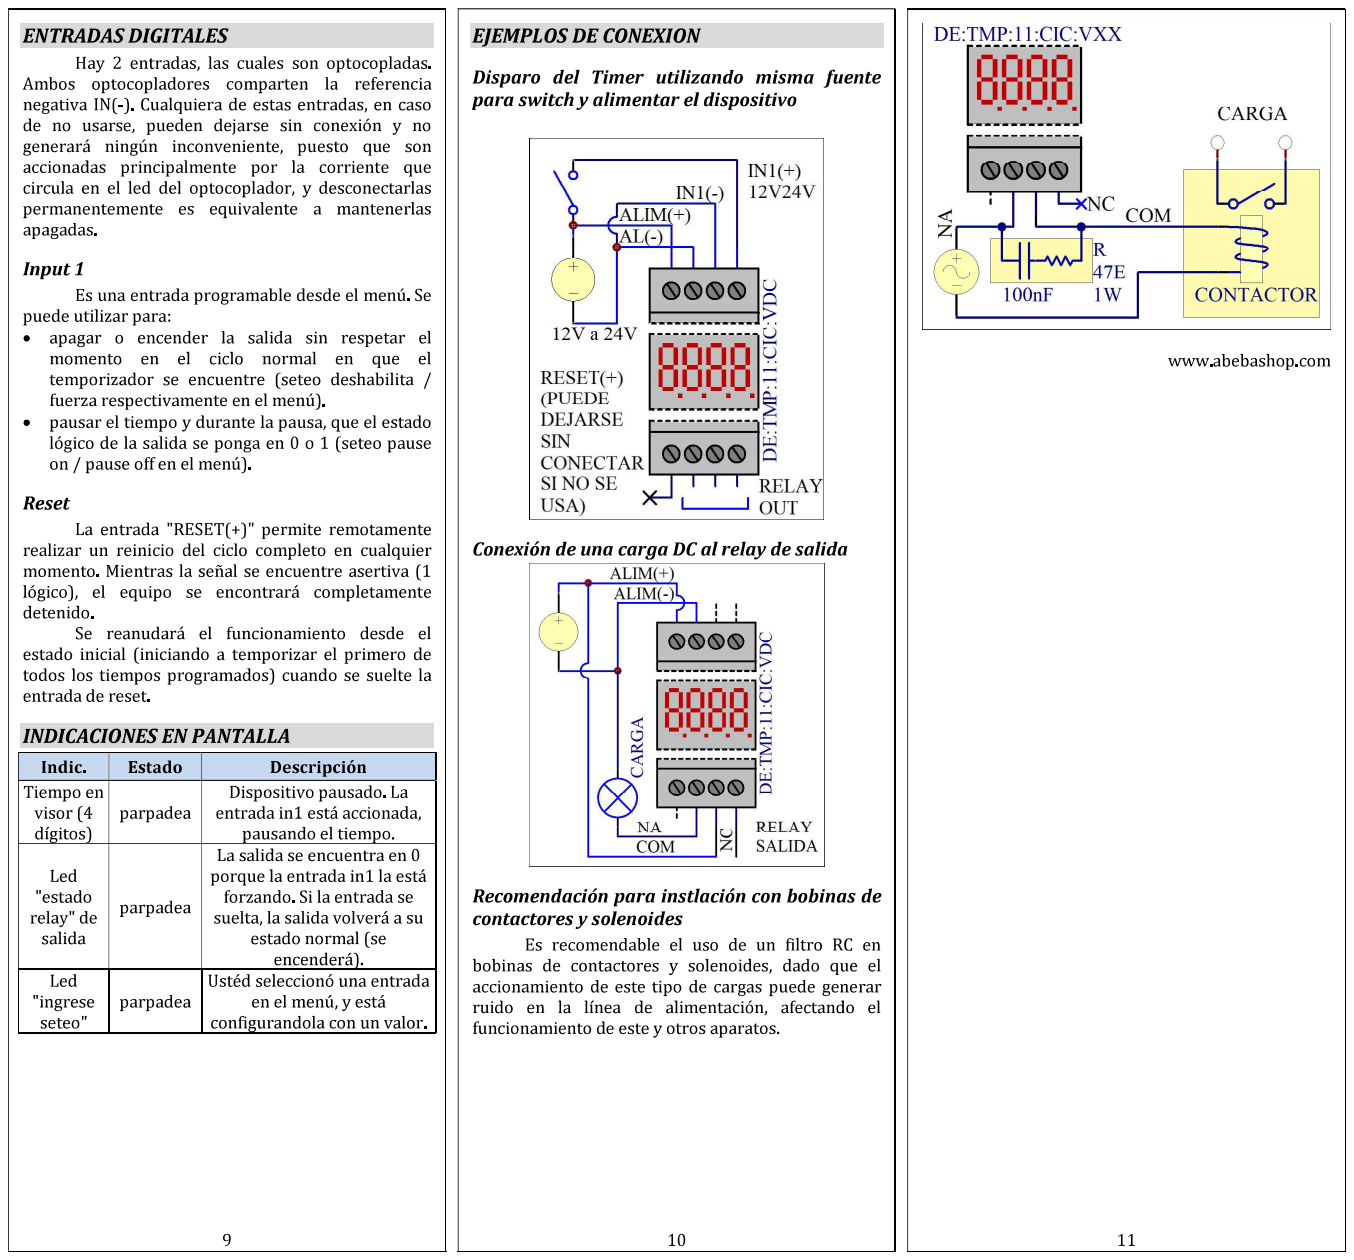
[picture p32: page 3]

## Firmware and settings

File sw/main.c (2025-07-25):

//==============================================================================
// Archivo: main.c
// Autor: Federico Ramos
// Modificado: 03-11-2023
//==============================================================================


//==============================================================================
// INCLUDE
#include <projectHeader.h>
#include <eeprom16f_memInitialization.h>
#include <eeprom16f.h>

#include <main.h>// Contiene fuses y otras cosas.
#include <system.h>// Para la inicialización del sistema.
#include <interrupts.h>
#include <t0.h>

#include <kPin.h>
#include <tmp_11.h>
#include <d7sm.h>
#include <fsm.h>
//==============================================================================

#include <t1.h>

// No lo puedo poner dentro de la acción a_showTime porque ésta solamente corre
// cuando está en "idle".
void driver_ledSet(void)
    {
    // Otro agregado: titileo led setting.
    if(tmp_11.flag_inputSettingLedBlink) LED14N = bitTitila;
    else LED14N = 0;
    }

//==============================================================================
// FUNCTION
//==============================================================================
void main(void)
	{
	char new_event;

	systemInit();
    FSM_INIT();

//tmp_11.flag_inputSettingLedBlink = 1;

	while(1)
		{
        //fsmParser();

        driver_ledSet();

        FSM_PARSER();

        D7SM_SCROLL_DRIVER();
		}
	}

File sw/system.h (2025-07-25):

//==============================================================================
// Archivo: system.h
// Autor: Federico Ramos
// Modificado: 16-11-2023 1359
//==============================================================================


//==============================================================================
// CONSTANT DEFINITIONS
#define INPUT 1
#define OUTPUT 0
//==============================================================================


//==============================================================================
// PINES UTILIZADOS
//==============================================================================
#define PUL0 RA0// Abajo derecha [SETEO]
#define LED5 RA1// Output led.
#define PUL1 RA2// Abajo izquierda [INCREMENTAR]
#define LED3 RA3// In1 led.
#define AN1 RA4
#define SEG_A RA5
#define SEG_D RA6
#define SEG_B RA7

#define IN1 RB0// In1 (optocoplada).
#define OUT RB1// Output.
#define IN2 RB2// In2 (optocoplada)
#define LED2 RB3// In2 led.
#define LED14N RB4// Input seting (led blink).
#define LED0 RB5// Desbloqueado.
#define LOCK RB6
#define UNUSED_RB7 RB7

#define AN2 RC0
#define AN0 RC1
#define SEG_DP RC2// In2 led (unused).
#define SEG_C RC3
#define SEG_E RC4
#define SEG_G RC5
#define SEG_F RC6
#define AN3 RC7

#define PUL2 RE3// Arriba derecha [ACEPTAR]


//==============================================================================
// DATA DIRECTION REGISTERS
//==============================================================================
#define DDR_PUL0 TRISA0
#define DDR_LED5 TRISA1
#define DDR_PUL1 TRISA2
#define DDR_LED3 TRISA3
#define DDR_AN1 TRISA4
#define DDR_SEG_A TRISA5
#define DDR_SEG_D TRISA6
#define DDR_SEG_B TRISA7

#define DDR_IN1 TRISB0
#define DDR_OUT TRISB1
#define DDR_IN2 TRISB2
#define DDR_LED2 TRISB3
#define DDR_LED14N TRISB4
#define DDR_LED0 TRISB5
#define DDR_LOCK TRISB6
#define DDR_UNUSED_RB7 TRISB7

#define DDR_AN2 TRISC0
#define DDR_AN0 TRISC1
#define DDR_SEG_DP TRISC2
#define DDR_SEG_C TRISC3
#define DDR_SEG_E TRISC4
#define DDR_SEG_G TRISC5
#define DDR_SEG_F TRISC6
#define DDR_AN3 TRISC7

#define DDR_PUL2 TRISE3


//==============================================================================
// MACROS
//==============================================================================
#define INIT_DDR()                                                             \
    {                                                                          \
    DDR_OUT=OUTPUT;                                                            \
    DDR_LED0=OUTPUT;                                                           \
    DDR_LED14N=OUTPUT;                                                         \
    DDR_LED2=OUTPUT;                                                           \
    DDR_LED3=OUTPUT;                                                           \
    DDR_LED5=OUTPUT;                                                           \
                                                                               \
    DDR_AN0=OUTPUT;                                                            \
    DDR_AN1=OUTPUT;                                                            \
    DDR_AN2=OUTPUT;                                                            \
    DDR_AN3=OUTPUT;                                                            \
                                                                               \
    DDR_SEG_A=OUTPUT;                                                          \
    DDR_SEG_B=OUTPUT;                                                          \
    DDR_SEG_C=OUTPUT;                                                          \
    DDR_SEG_D=OUTPUT;                                                          \
    DDR_SEG_E=OUTPUT;                                                          \
    DDR_SEG_F=OUTPUT;                                                          \
    DDR_SEG_G=OUTPUT;                                                          \
    DDR_SEG_DP=OUTPUT;                                                         \
                                                                               \
    DDR_PUL0=INPUT;                                                            \
    DDR_PUL1=INPUT;                                                            \
    DDR_PUL2=INPUT;                                                            \
    }

#define INIT_PORTS()                                                           \
    {                                                                          \
    PORTA=0XFF;                                                                \
    PORTB=0XFF;                                                                \
    PORTC=0XFF;                                                                \
    PORTE=0XFF;                                                                \
    OUT=0;                                                                     \
    LED0=0;                                                                    \
    LED14N=1;                                                                  \
    LED2=0;                                                                    \
    LED3=0;                                                                    \
    LED5=0;                                                                    \
    AN0=0;                                                                     \
    AN1=0;                                                                     \
    AN2=0;                                                                     \
    AN3=0;                                                                     \
    }


#define DISABLE_COMPARATOR()                                                   \
    {                                                                          \
    CM0=1;                                                                     \
    CM1=1;                                                                     \
    CM2=1;                                                                     \
    }

// Si no se va a usar el A/D, esta función se debe invocar, ya que por defecto,
// luego del reset, los puertos de entrada comienzan como entradas analógicas pa
// ra ser usadas con el A/D, lo cual deshabilita que funcionen como entradas/sal
// idas digitales.
#define DISABLE_AD() {                                                         \
    ANS0=0;                                                                    \
    ANS1=0;                                                                    \
    ANS2=0;                                                                    \
    ANS3=0;                                                                    \
    ANS4=0;                                                                    \
    }
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

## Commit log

2025-07-25 cambio de directorio
2025-07-25 addition of sources
    [fsm.SchDoc]
2025-07-25 include files again
    [componentes.xlsx, curvas.SchDoc, diagrama_interior.SchDoc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]
2025-07-25 added prjpcb
    [main40v.PrjPcb, ucExpandido.PrjPcb]
2026-05-15 agregado leyenda version
    [disp4x7seg.PrjPcb]
